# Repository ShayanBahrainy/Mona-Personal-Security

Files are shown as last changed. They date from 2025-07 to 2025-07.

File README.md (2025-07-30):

# Photos
#### Final build photos
SIDE
FRONT
TOP

#### Old Broken Setup


#### Driver code
driver

#### Wiring Diagram
Screenshot From 2025-07-29 18-49-31

# Mona Personal Security
A self-honing turret which uses a camera and OpenCV in order to detect faces and autonomously move the turret to shoot projectiles at them.
The name, is of course, an ode to Mona, who accompanied us for many hours in GitHub HQ.

# Software
There are two parts to the software, the driver code that runs the camera from your laptop, and the firmware in the Raspberry Pico that recieves instructions and moves the motors.
The driver code needs to be launched after the firmware has been flashed, and the device connected via USB. Change the serial_port variable used in driver.py accordingly. Run the code, and tinker with camera_index until it works. (Usually, 0 or 1). The firmware should be flashed with Arduino IDE, we tested with version 2.3.6

# CAD
In CAD, we created the top of the main structure, the bottom, and the middle as individual components. We also created the piece to go on the railing and hold the motors for shooting. There was also a mount we created that hooks into the top of the main structure. This is where we bolted in the webcam.

# Challenges
We struggled with getting the stepper motor to work, but after many hours, and some outside help, we realized that the board, a XIAO RP2040 was fried, and we switched to a Raspberry Pi Pico. This was our biggest problem, the stepper motor held us back several times. The servos also weren't working for whatever reason, they didn't move no matter what the code did. The motors on the arm worked just fine though. Our issues were solved about a minute after the video was taken, after we fixed a single wire.

# Demo
https://youtu.be/geNfsmsPVWY

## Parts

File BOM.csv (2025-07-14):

Item Name | Quantity
Stepper Motor (Nema17) | 1
Motor driver | 1
Filament | 40 grams
Orpheus Pico | 1
Servo (MG996R) | 2
Aluminum extrusion | 1
Wires | 18
USB Webcam | 1
Buck converter | 1
Capacitor | 1
Button | 1
DC converter power supply | 1
Power input board | 1

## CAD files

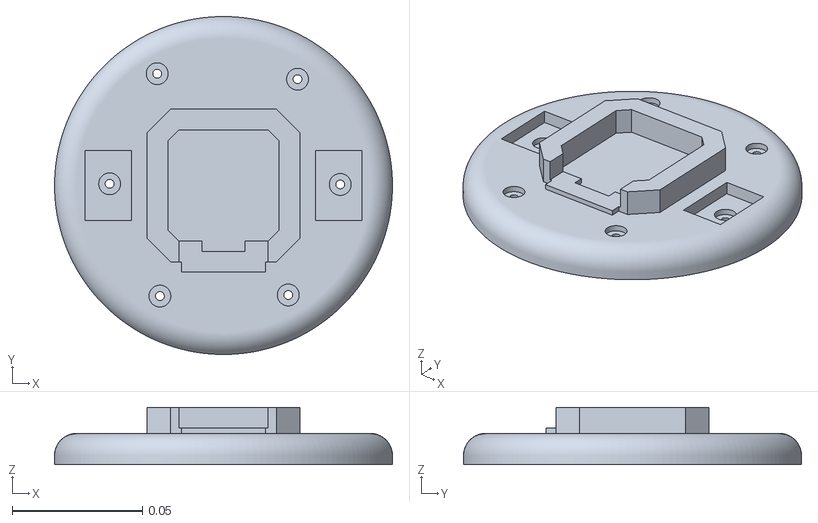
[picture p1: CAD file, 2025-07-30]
CAD Components/Mona Personal Security - Base.stl
0.13 x 0.13 x 0.022

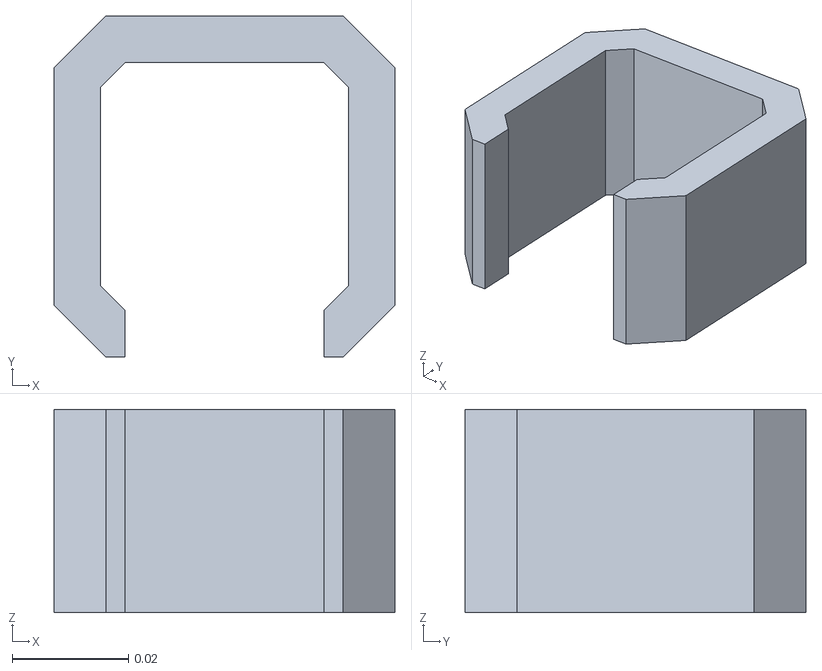
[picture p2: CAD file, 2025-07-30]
CAD Components/Mona Personal Security - Midpiece.stl
0.0587 x 0.0587 x 0.035

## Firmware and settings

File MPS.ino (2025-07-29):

#include <Stepper.h>
#include <Servo.h>



#define STEP 300

Stepper stepper(STEP,11,10);  
Servo servo_1; // create servo object to control a servo
Servo servo_2;


void move_arm(int position) {
  servo_1.write(position);
  servo_2.write(-position);
}

const int MAX_ROTATION = 600;
int rotation = 0;
int dir = 1;
int increment = 10;

void setup() {
  pinMode(6, OUTPUT);
  servo_1.attach(3);
  servo_2.attach(4);
  delay(1000);
  stepper.setSpeed(30);
  move_arm(120);
}


void loop() {
 if (!Serial.available()) {
    if (abs(rotation) > MAX_ROTATION) {
      dir *= -1;
    }
    rotation += increment * dir;
    stepper.step(increment * dir);
    return;
 }
 String x_ratio_string = Serial.readStringUntil('\n');
 String y_ratio_string = Serial.readStringUntil('\n');
 bool shoot = Serial.readStringUntil('\n') == "True";
 float x_ratio = std::atof(x_ratio_string.c_str());
 float y_ratio = std::atof(y_ratio_string.c_str());
 rotation += increment * x_ratio;
 stepper.step(increment * x_ratio);
 move_arm(120);
 if (shoot) {
  digitalWrite(6, HIGH);
  delay(1000);
  digitalWrite(6, LOW);
 }
 
}

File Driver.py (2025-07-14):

from types import NoneType
import serial
import cv2shootcount = 0
vc = cv2.VideoCapture(1)
vc.read()
size = (int(vc.get(cv2.CAP_PROP_FRAME_WIDTH)), int(vc.get(cv2.CAP_PROP_FRAME_HEIGHT)))
fd = cv2.FaceDetectorYN.create("face_detection_yunet_2023mar.onnx","",size)
pico = serial.Serial('COM10', 115200, timeout=1)
while True:
    success, image = vc.read()
    if not success:
        print("Error readxing image")
        break
    success, faces = fd.detect(image)
    if not success:
        print("Error detecting faces")
        break
    if type(faces) != NoneType:
        for face in faces:
            image = cv2.rectangle(image, [int(face[0]), int(face[1]), int(face[2]), int(face[3])], (255, 0, 255))        midpoint = (size[0]/2,size[1]/2)
        delta_x = faces[0][8] - midpoint[0]
        delta_y = faces[0][9] - midpoint[1]
        shoot = False
        if abs(delta_x) < 20:
            x_ratio = 0
            shootcount += 1
        else:
            x_ratio = delta_x / midpoint[0] #Distance from middle as ratio of maximum possible distance
        if abs(delta_y) < 100:
            y_ratio = 0
        else:
            y_ratio = delta_y / midpoint[1]
        if shootcount == 10:
            shoot = True
            shootcount = 0
        pico.write(f"{x_ratio:.3f}\n{y_ratio:.3f}\n{shoot}\n".encode())
        print(x_ratio, y_ratio)
    cv2.imshow("Face detection", image)
    if (cv2.waitKey(5) >= 0):
        break
vc.release()

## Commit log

2025-07-14 Update and rename bom.csv to BOM.csv
    [BOM.csv]
2025-07-14 Create CAD
2025-07-29 Add cad file
2025-07-30 Added wiring diagram
2025-07-30 added stl
2025-07-30 CAD components
    [Mona Personal Security - Base.stl, Mona Personal Security - Midpiece.stl]
